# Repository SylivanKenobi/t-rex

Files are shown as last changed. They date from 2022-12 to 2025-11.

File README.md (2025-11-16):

# T-Rex

A 5x12 Ortholinear QMK and ZMK compatible Keyboard. The keyboard is designed to be easily ordered by anyone from a PCB manufacturer and assembled by yourself. It is compatible with Pro Micro controllers and their derivatives. Additionally, it supports WS2812 LED strips as an extra feature. The keyboard comes with an assortment of 3D printable cases and can be assembled with easily available parts. 

QMK Firmware is currently only on this fork of [qmk](https://github.com/SylivanKenobi/qmk_firmware/tree/master/keyboards/t_rex). 

The [ZMK](https://github.com/devilzmods/trex_shield_module) implementation supports Bluetooth and ZMK Studio with [compatible controllers](https://zmk.dev/docs/hardware#pro_micro). 

Example parts:
* [QMK Controller](https://splitkb.com/products/pro-micro-atmega32u4-5v-16mhz)
* [ZMK Controller (Wireless)](https://de.aliexpress.com/item/1005007266112508.html)
* [Diodes](https://splitkb.com/products/tht-diodes)
* [Reset button](https://mechboards.co.uk/products/reset-switches?variant=40823623090381)
* 60 Switches
* 60 Keycaps
* 6x [M2x8 Standoffs](https://splitkb.com/products/brass-m2-spacers?variant=42396969173251)
* 3D printed case([stl file](cases/minimal-case.stl))
* 6x M2x10 screws, 6x M2x5 screws

## Assembly

### PCB

1. Solder diodes on top of board, orientation is marked by silkscreen
1. Clip diode leftovers
1. Solder controller headers and reset button
1. Solder switches
1. Solder controller
1. [Flash QMK](https://github.com/SylivanKenobi/qmk_firmware/tree/master/keyboards/t_rex)
1. [Or ZMK](firmware/t_rex_zmk_studio.uf2) - Download the .uf2 file, put the board into its bootloader by double tapping reset and copy the firmware file onto the controller.
1. For wireless, solder a battery (3,7V LiIon) or battery connector and power switch to the battery pins on the nice!nano.

> If you socket your controller, mount the controller before the switches and test the PCB.

### Cases

#### Minimal Case

1. Print [case](cases/minimal-case.stl) with 3d printer
1. Mount standoffs with M2x5 from the top
1. Mount case with M2x10 to standoffs

#### Closed Case

1. Print the case, depending on printer size you can either use the regular or the split version of the case.([case files](cases/closed-falt-case)) 
1. Insert M2x4x3.5 Heat set inserts([exapmle](https://www.bastelgarage.ch/gewindeeinsatze-messing-insert-set-360-stuck))
1. Mount pcb to case with M2x5 screws

#### Slab Case

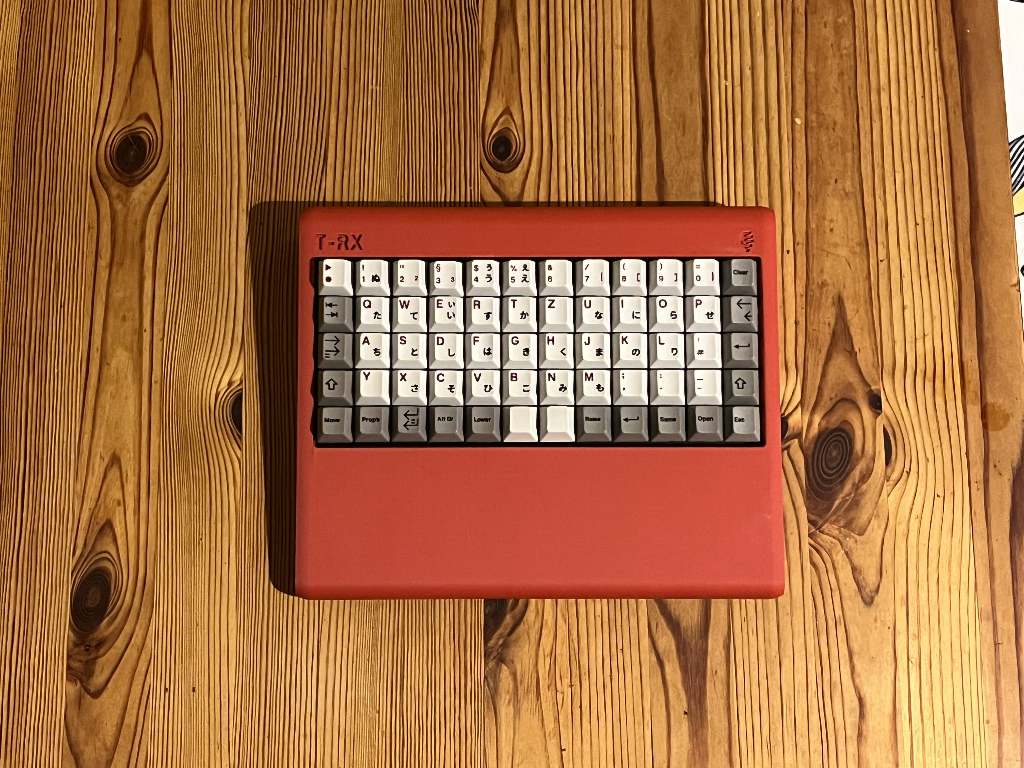
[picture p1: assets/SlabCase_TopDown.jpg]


1. Print the case, the .3mf file includes bodies for the lettering and Logo that can be colored for multicolor printing, removed for embossed text or ignored to fill the text in. Make sure the lid body sits flush on the build plate or print it separately. Only the main  Tray area of the case needs support, the battery cover can be printed in place as built-in support and popped out.[case file](cases/slabcase.3mf)
1. After printing remove the support and carefully break free the battery cover
1. Fill the case with your Medium of choice. Sand with a grain size of <2mm is recommended, other options include cement and plaster. The internal volume of the case is rougly .7 liter. Glue the lid on top and make sure it's tight in case your medium could spill out.
1. Mount 8mm standoffs to PCB with M2x5/6 from the top
1. Mount case with M2x5/6 to standoffs, if applicable route the battery connector wire into the battery tray.

## Plate

I would recommend using PCB-Mounted switches for this board. There is a 3d printable plate for the t-rex in this repo([file](cases/plate.stl)). The plate works but because it's 3d printed it's not that great.

## Customizing Firmware

(ZMK Studio)[https://zmk.studio/] allows on the fly remapping of your keyboards keymap, similar to via/vial. For more in-depth configuration you can follow the (ZMK Customization Guide)[https://zmk.dev/docs/customization] to create your own config repo and add the (T-Rex Shield Module)[https://github.com/devilzmods/trex_shield_module]

## Roadmap

1. Merge firmware to QMK

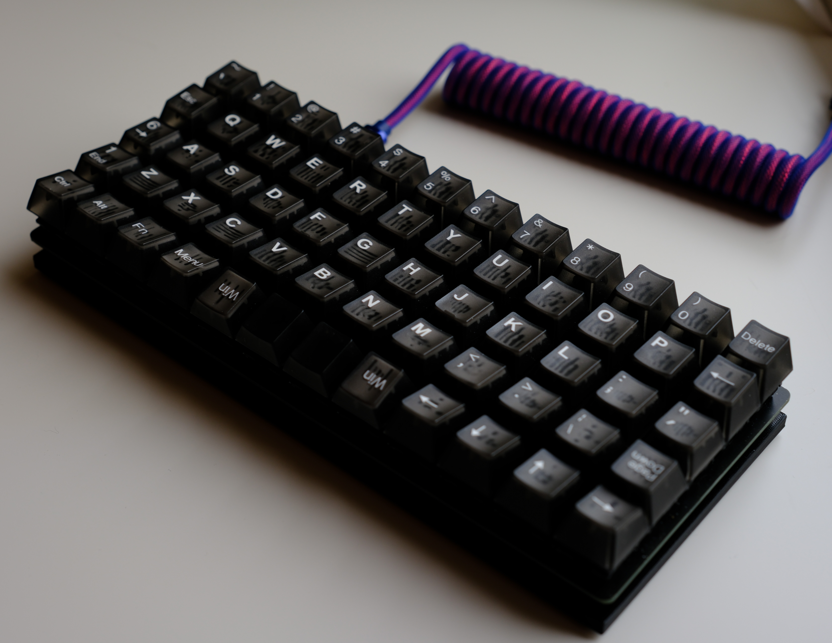
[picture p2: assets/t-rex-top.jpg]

image of keyboard backside

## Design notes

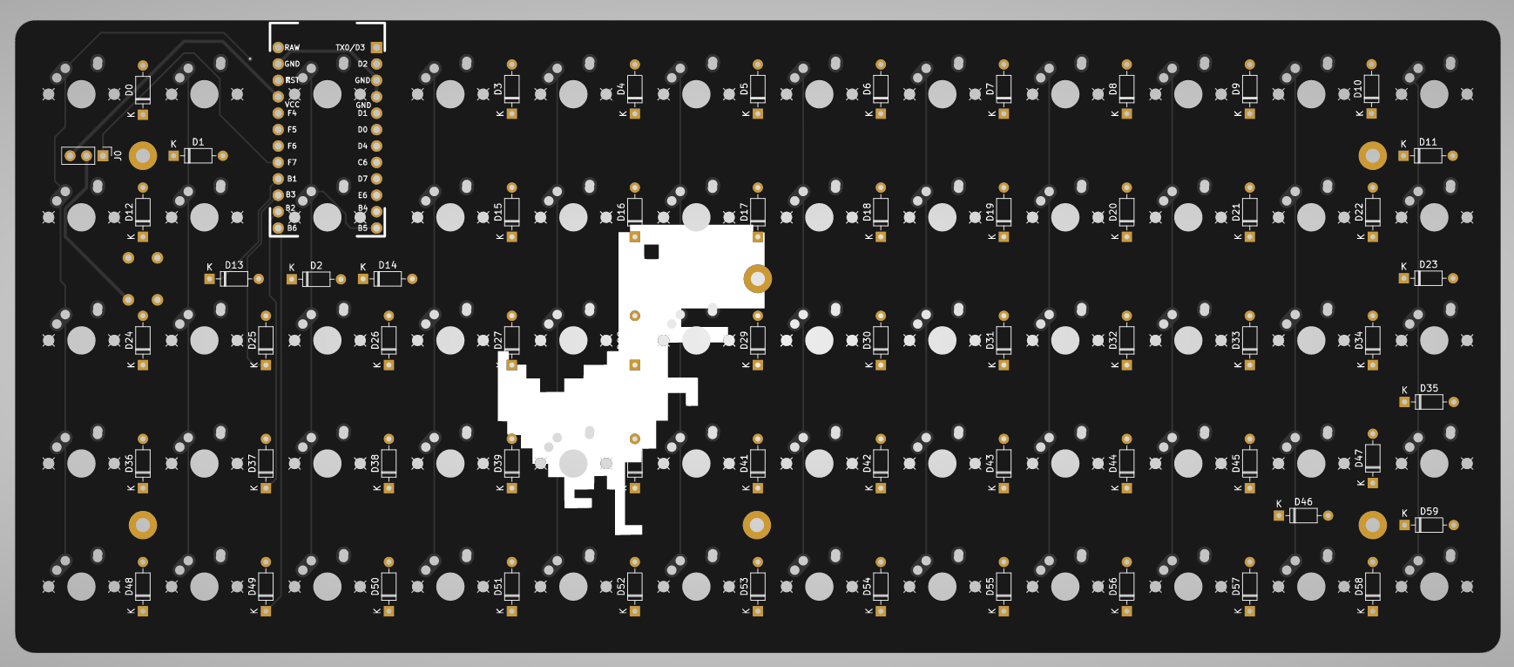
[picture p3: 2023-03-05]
assets/pcb.png

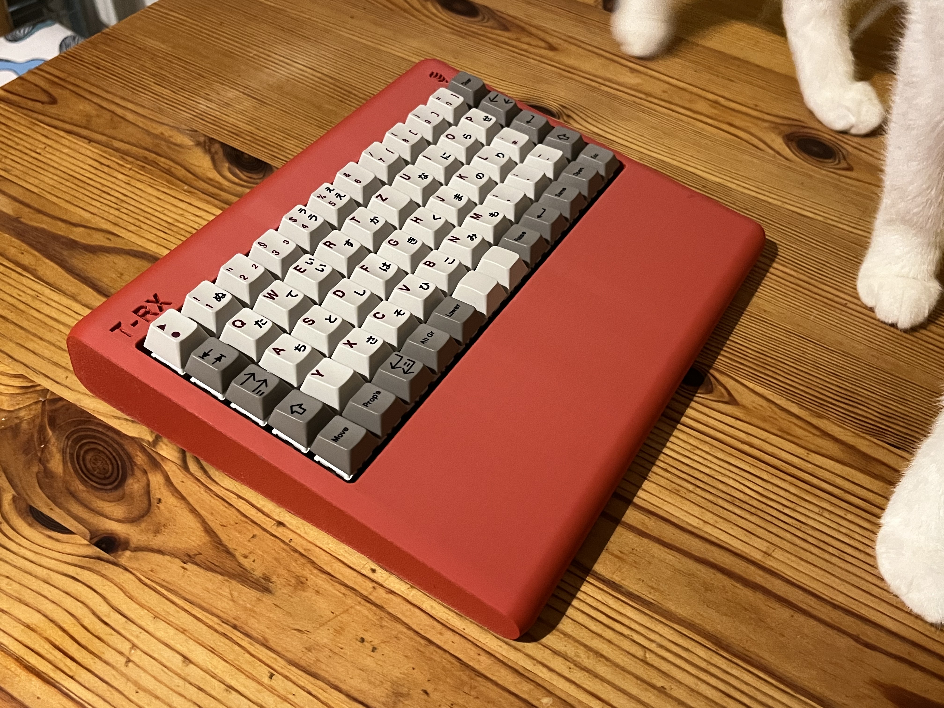
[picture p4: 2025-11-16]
assets/SlabCase_SideView.jpg

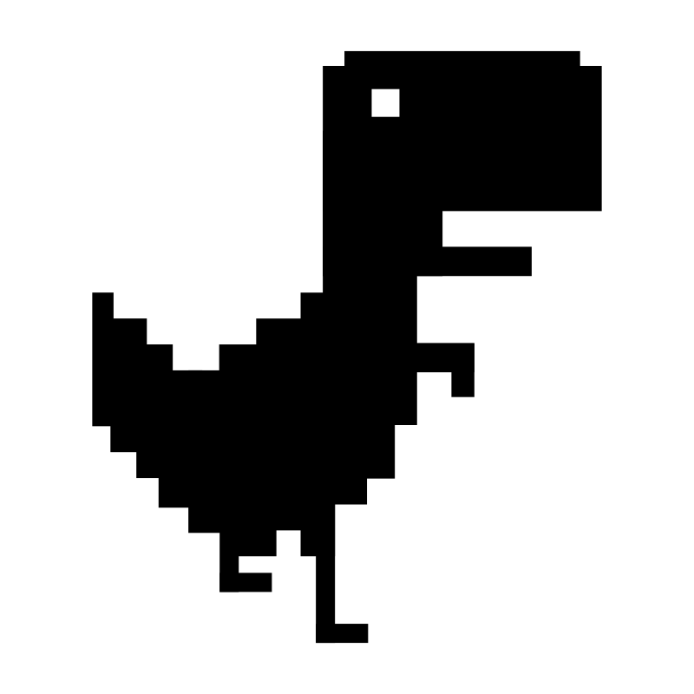
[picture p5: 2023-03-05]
assets/logo.png

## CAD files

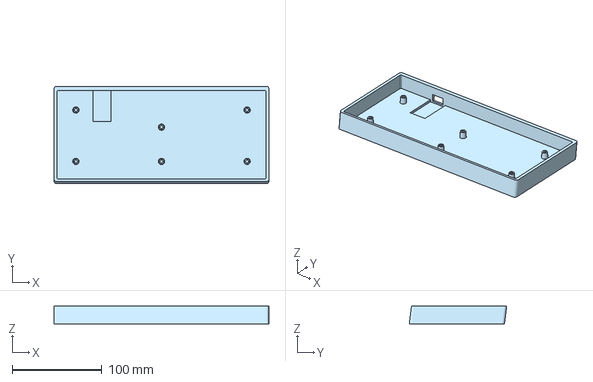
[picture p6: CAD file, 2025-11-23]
cases/closed-falt-case/regular-closed.3mf
239.2 x 108.4 x 19.9 mm

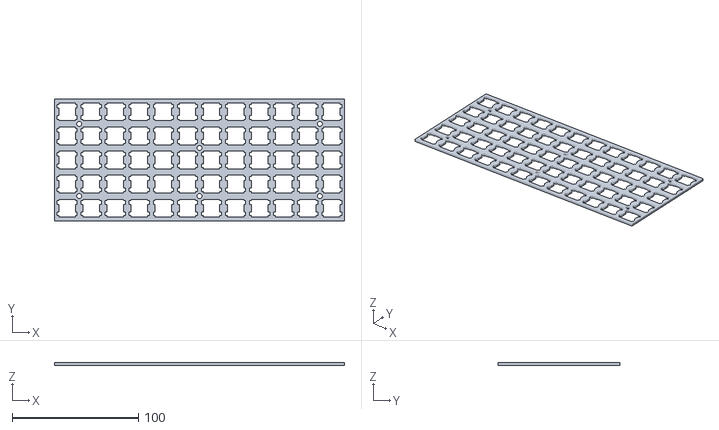
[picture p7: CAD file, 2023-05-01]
cases/plate.stl
229.6 x 96.2 x 2.00

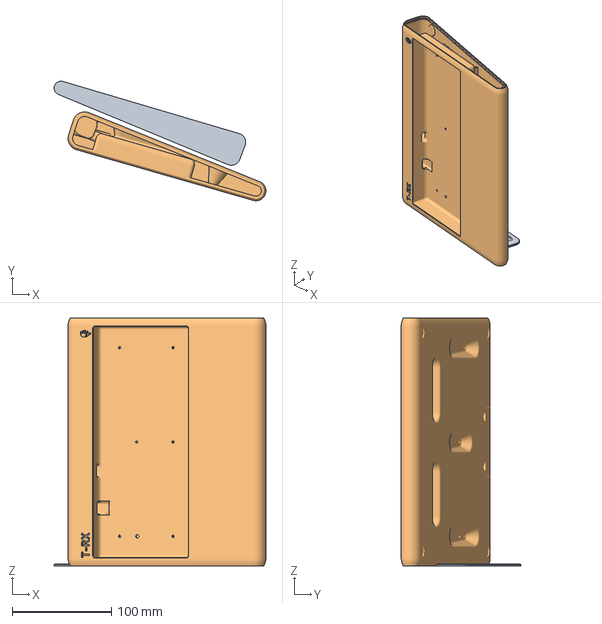
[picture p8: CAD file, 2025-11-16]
cases/slab-case/slab-case.3mf
213.4 x 120.5 x 249.8 mm
RetroWedge Lid.stl
RetroWedge v24_A

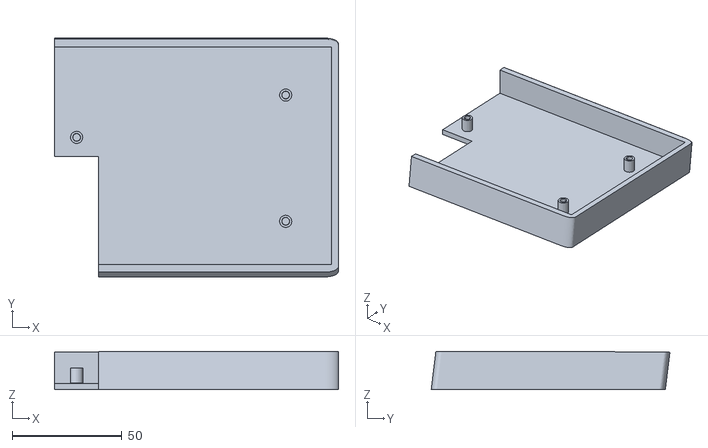
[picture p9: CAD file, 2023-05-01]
cases/closed-falt-case/split-closed-right.stl
129.5 x 108.9 x 17.5

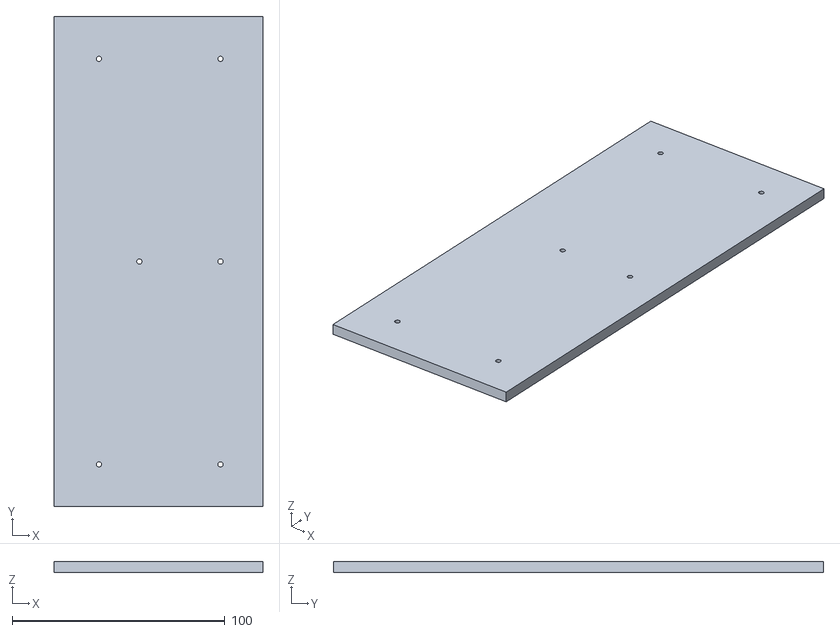
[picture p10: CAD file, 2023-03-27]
cases/minimal-case.stl
98.0 x 230.2 x 5.00

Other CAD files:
cases/closed-falt-case/split-closed-left.stl

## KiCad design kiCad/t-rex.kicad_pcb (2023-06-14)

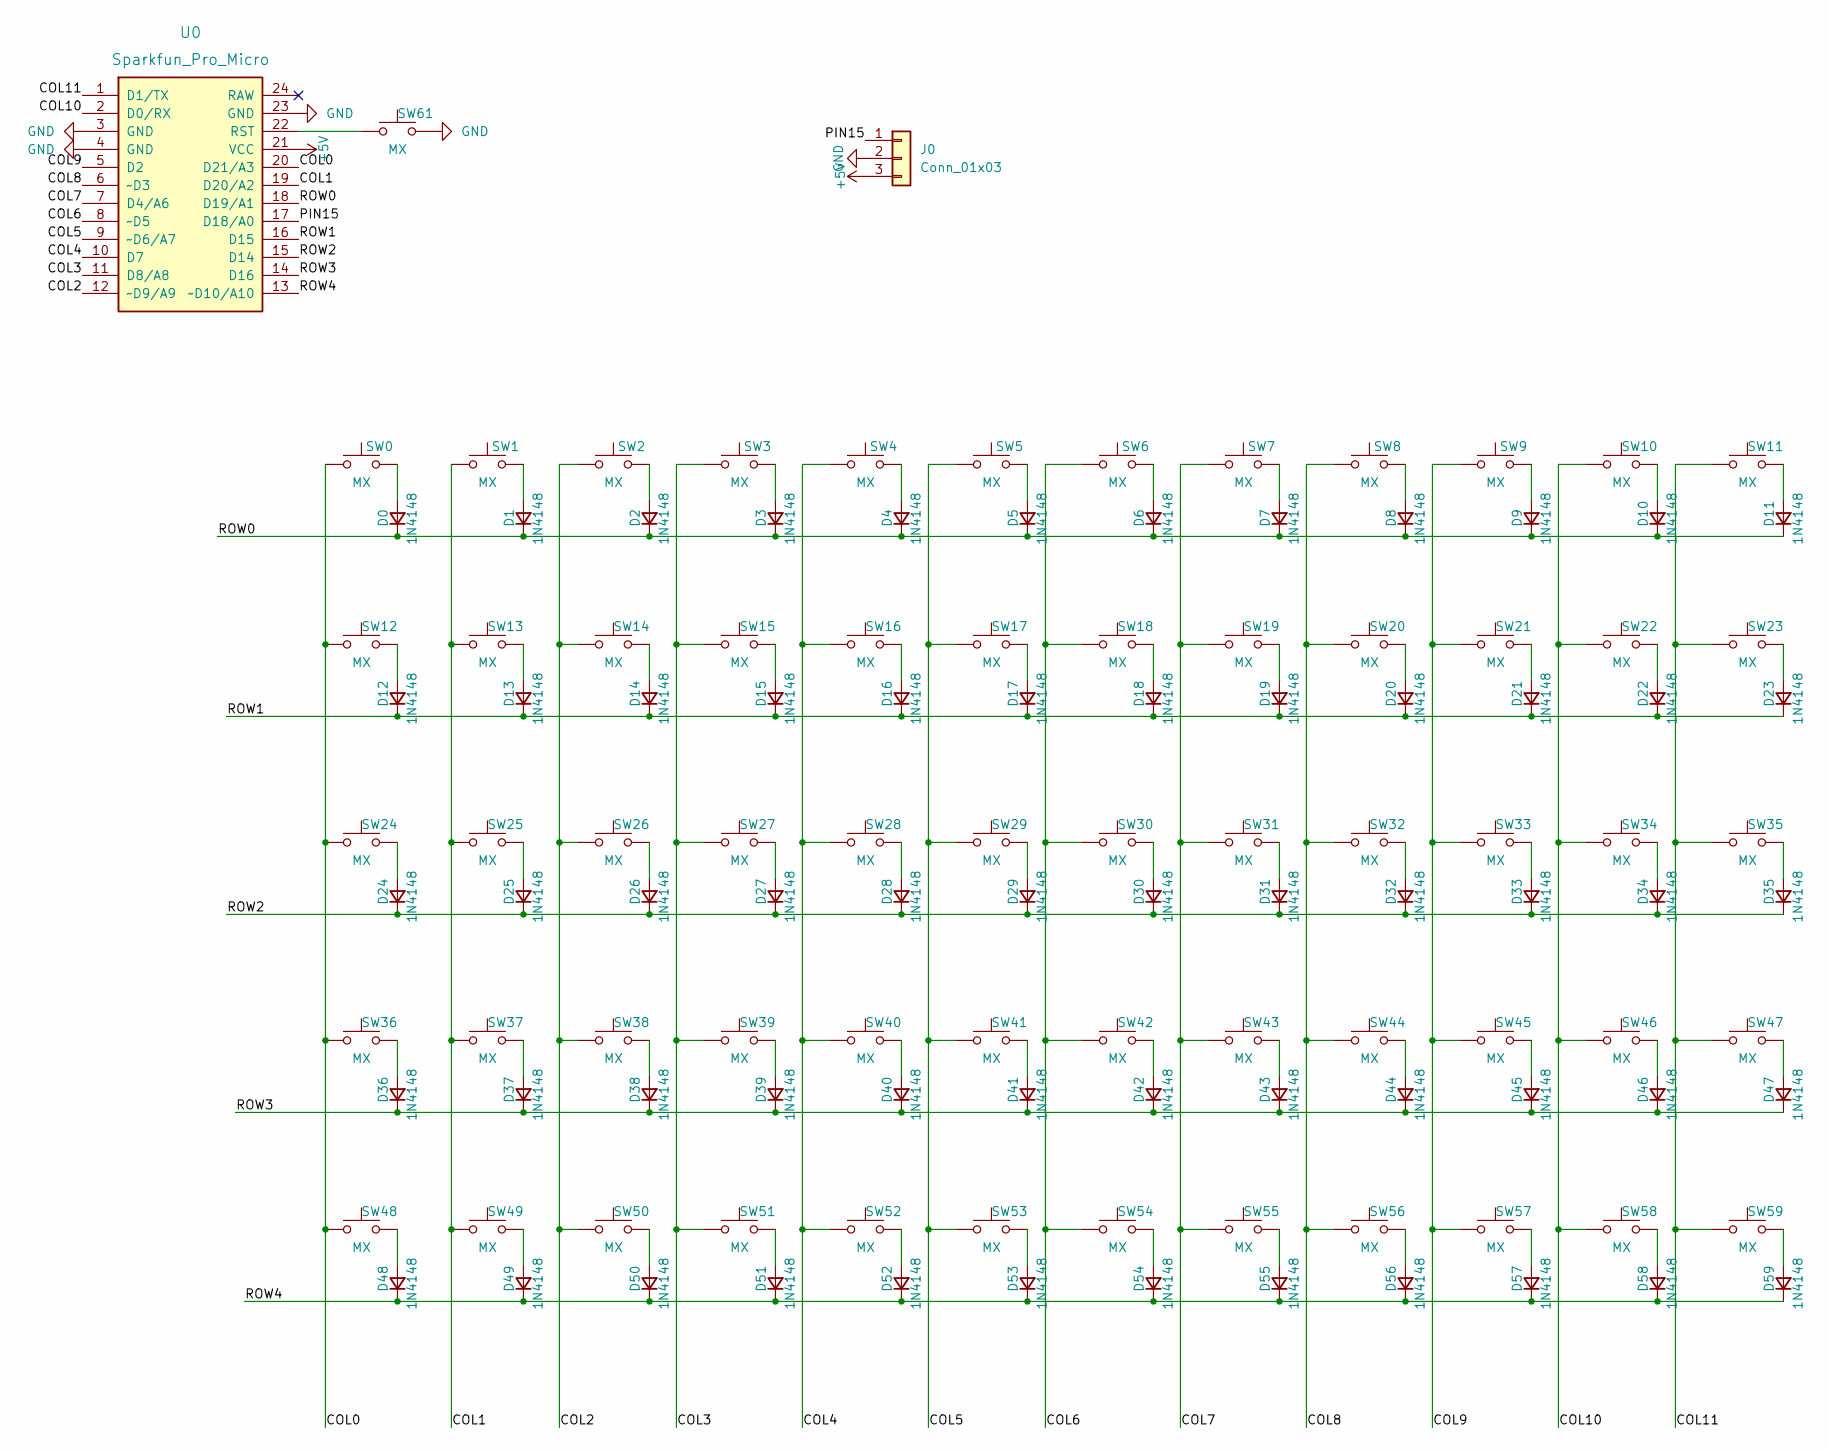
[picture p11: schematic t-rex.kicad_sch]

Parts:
D0, D1, D2, D3, D4, D5, D6, D7, D8, D9, D10, D11, D12, D13, D14, D15, D16, D17, D18, D19, D20, D21, D22, D23, D24, D25, D26, D27, D28, D29, D30, D31, D32, D33, D34, D35, D36, D37, D38, D39, D40, D41, D42, D43, D44, D45, D46, D47, D48, D49, D50, D51, D52, D53, D54, D55, D56, D57, D58, D59: 1N4148; D_DO-35_SOD27_P7.62mm_Horizontal
J0: Conn_01x03; PinHeader_1x03_P2.54mm_Vertical
SW0, SW1, SW2, SW3, SW4, SW5, SW6, SW7, SW8, SW9, SW10, SW11, SW12, SW13, SW14, SW15, SW16, SW17, SW18, SW19, SW20, SW21, SW22, SW23, SW24, SW25, SW26, SW27, SW28, SW29, SW30, SW31, SW32, SW33, SW34, SW35, SW36, SW37, SW38, SW39, SW40, SW41, SW42, SW43, SW44, SW45, SW46, SW47, SW48, SW49, SW50, SW51, SW52, SW53, SW54, SW55, SW56, SW57, SW58, SW59: MX; MX-1U-NoLED
SW61: MX; PushButton_6x6mm_TH_Pretty
U0: Sparkfun_Pro_Micro; ArduinoProMicro

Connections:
+5V: J0.3, U0.21 (VCC)
/COL0: SW0.1, SW12.1, SW24.1, SW36.1, SW48.1, U0.20 (D21/A3)
/COL1: SW1.1, SW13.1, SW25.1, SW37.1, SW49.1, U0.19 (D20/A2)
/COL2: SW2.1, SW14.1, SW26.1, SW38.1, SW50.1, U0.12 (~D9/A9)
/COL3: SW3.1, SW15.1, SW27.1, SW39.1, SW51.1, U0.11 (D8/A8)
/COL4: SW4.1, SW16.1, SW28.1, SW40.1, SW52.1, U0.10 (D7)
/COL5: SW5.1, SW17.1, SW29.1, SW41.1, SW53.1, U0.9 (~D6/A7)
/COL6: SW6.1, SW18.1, SW30.1, SW42.1, SW54.1, U0.8 (~D5)
/COL7: SW7.1, SW19.1, SW31.1, SW43.1, SW55.1, U0.7 (D4/A6)
/COL8: SW8.1, SW20.1, SW32.1, SW44.1, SW56.1, U0.6 (~D3)
/COL9: SW9.1, SW21.1, SW33.1, SW45.1, SW57.1, U0.5 (D2)
/COL10: SW10.1, SW22.1, SW34.1, SW46.1, SW58.1, U0.2 (D0/RX)
/COL11: SW11.1, SW23.1, SW35.1, SW47.1, SW59.1, U0.1 (D1/TX)
/PIN15: J0.1, U0.17 (D18/A0)
/ROW0: D0.1 (K), D1.1 (K), D2.1 (K), D3.1 (K), D4.1 (K), D5.1 (K), D6.1 (K), D7.1 (K), D8.1 (K), D9.1 (K), D10.1 (K), D11.1 (K), U0.18 (D19/A1)
/ROW1: D12.1 (K), D13.1 (K), D14.1 (K), D15.1 (K), D16.1 (K), D17.1 (K), D18.1 (K), D19.1 (K), D20.1 (K), D21.1 (K), D22.1 (K), D23.1 (K), U0.16 (D15)
/ROW2: D24.1 (K), D25.1 (K), D26.1 (K), D27.1 (K), D28.1 (K), D29.1 (K), D30.1 (K), D31.1 (K), D32.1 (K), D33.1 (K), D34.1 (K), D35.1 (K), U0.15 (D14)
/ROW3: D36.1 (K), D37.1 (K), D38.1 (K), D39.1 (K), D40.1 (K), D41.1 (K), D42.1 (K), D43.1 (K), D44.1 (K), D45.1 (K), D46.1 (K), D47.1 (K), U0.14 (D16)
/ROW4: D48.1 (K), D49.1 (K), D50.1 (K), D51.1 (K), D52.1 (K), D53.1 (K), D54.1 (K), D55.1 (K), D56.1 (K), D57.1 (K), D58.1 (K), D59.1 (K), U0.13 (~D10/A10)
GND: J0.2, SW61.2, U0.3 (GND), U0.4 (GND), U0.23 (GND)
unnamed: D0.2 (A), SW0.2
unnamed: D1.2 (A), SW1.2
unnamed: D2.2 (A), SW2.2
unnamed: D3.2 (A), SW3.2
unnamed: D4.2 (A), SW4.2
unnamed: D5.2 (A), SW5.2
unnamed: D6.2 (A), SW6.2
unnamed: D7.2 (A), SW7.2
unnamed: D8.2 (A), SW8.2
unnamed: D9.2 (A), SW9.2
unnamed: D10.2 (A), SW10.2
unnamed: D11.2 (A), SW11.2
unnamed: D12.2 (A), SW12.2
unnamed: D13.2 (A), SW13.2
unnamed: D14.2 (A), SW14.2
unnamed: D15.2 (A), SW15.2
unnamed: D16.2 (A), SW16.2
unnamed: D17.2 (A), SW17.2
unnamed: D18.2 (A), SW18.2
unnamed: D19.2 (A), SW19.2
unnamed: D20.2 (A), SW20.2
unnamed: D21.2 (A), SW21.2
unnamed: D22.2 (A), SW22.2
unnamed: D23.2 (A), SW23.2
unnamed: D24.2 (A), SW24.2
unnamed: D25.2 (A), SW25.2
unnamed: D26.2 (A), SW26.2
unnamed: D27.2 (A), SW27.2
unnamed: D28.2 (A), SW28.2
unnamed: D29.2 (A), SW29.2
unnamed: D30.2 (A), SW30.2
unnamed: D31.2 (A), SW31.2
unnamed: D32.2 (A), SW32.2
unnamed: D33.2 (A), SW33.2
unnamed: D34.2 (A), SW34.2
unnamed: D35.2 (A), SW35.2
unnamed: D36.2 (A), SW36.2
unnamed: D37.2 (A), SW37.2
unnamed: D38.2 (A), SW38.2
unnamed: D39.2 (A), SW39.2
unnamed: D40.2 (A), SW40.2
unnamed: D41.2 (A), SW41.2
unnamed: D42.2 (A), SW42.2
unnamed: D43.2 (A), SW43.2
unnamed: D44.2 (A), SW44.2
unnamed: D45.2 (A), SW45.2
unnamed: D46.2 (A), SW46.2
unnamed: D47.2 (A), SW47.2
unnamed: D48.2 (A), SW48.2
unnamed: D49.2 (A), SW49.2
unnamed: D50.2 (A), SW50.2
unnamed: D51.2 (A), SW51.2
unnamed: D52.2 (A), SW52.2
unnamed: D53.2 (A), SW53.2
unnamed: D54.2 (A), SW54.2
unnamed: D55.2 (A), SW55.2
unnamed: D56.2 (A), SW56.2
unnamed: D57.2 (A), SW57.2
unnamed: D58.2 (A), SW58.2
unnamed: D59.2 (A), SW59.2
unnamed: SW61.1, U0.22 (RST)

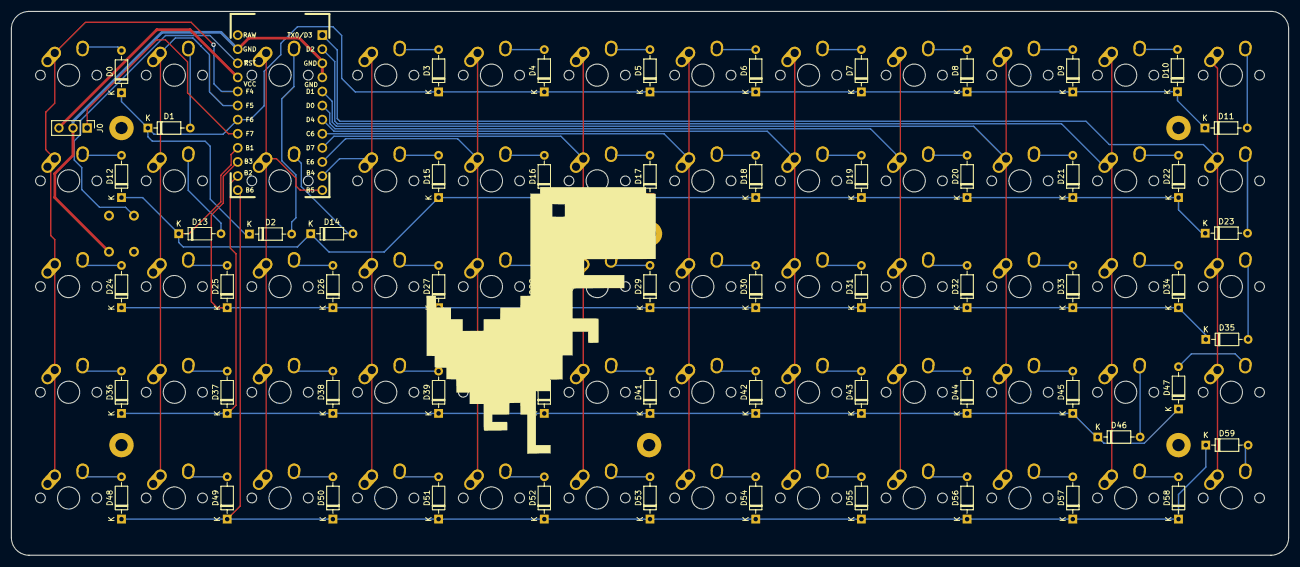
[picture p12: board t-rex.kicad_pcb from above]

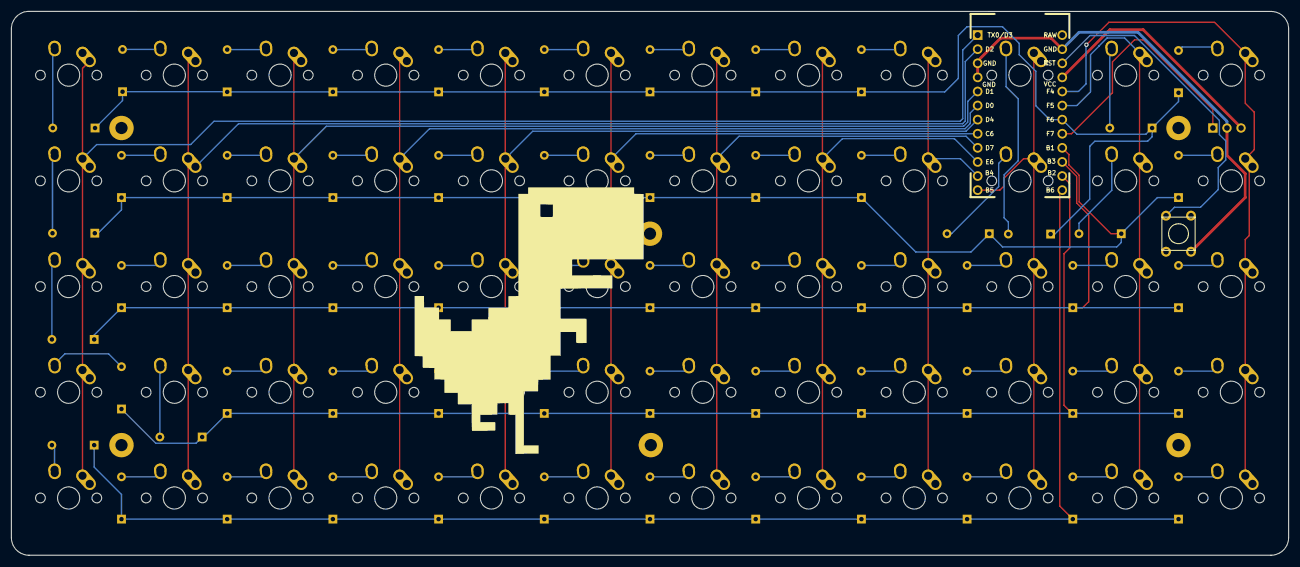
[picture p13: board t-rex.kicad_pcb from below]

Board: 2 copper layers, 230.2 x 98.0 mm, 123 parts (2 on the bottom side), 81 nets.

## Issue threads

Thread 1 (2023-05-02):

One piece case please

tangbonze, 2023-05-02:
Could you please share one piece case file? Thanks a lot.

SylivanKenobi, 2023-05-02:
Yeah i will do this probably this weekend

tangbonze, 2023-05-02:
Thank you！

SylivanKenobi, 2023-05-06:
I added it:
https://github.com/SylivanKenobi/t-rex/blob/main/cases/closed-falt-case/regular-closed.stl

Closed 2023-05-06.

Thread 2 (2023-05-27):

WS2812B support

iamagithublearner, 2023-05-27:
Hey can you please help me with configuring the WS2812B leds? where do i start?

SylivanKenobi, 2023-05-28:
Yeah sure I just start at the beginning. There are three holes on the left side of the board. The square one is data, middle is ground and the other is power. In the t-rex firmware the leds are enabled by  default. You have to configure the amount of leds that you install [here](https://github.com/SylivanKenobi/qmk_firmware/blob/343a26f16749af895945b1a97527ff421265a8eb/keyboards/t_rex/info.json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) . Everything for the leds can be configured in the [info.json](https://github.com/SylivanKenobi/qmk_firmware/blob/master/keyboards/t_rex/info.json) you can find the qmk docs for it [here](https://github.com/qmk/qmk_firmware/blob/master/docs/reference_info_json.md#rgb-lighting). Does this answer your questions or do you need something more specific?

SylivanKenobi, 2023-06-14:
I close this Issue as there was no further input for two weeks.

Closed 2023-06-14.

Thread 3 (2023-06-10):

Minimal Case

AbhinashPatro, 2023-06-10:
Hi Sylivan, How do you mount pcb to the case though ? Your PCB Gerber files contain no holes on the PCB but the picture of the back of the PCB shows the holes for passing the standoff. I am little confused on this .

SylivanKenobi, 2023-06-14:
This is a mistake. It looks like in the process of updating to kicad 7 the holes for the case mounting got lost. I will fix this today.

SylivanKenobi, 2023-06-14:
The holes are back. [Commit](https://github.com/SylivanKenobi/t-rex/commit/68a8e1d2b7005a494b37ec6a024ebed064c535c4) fixes this.

AbhinashPatro, 2023-06-18:
Thanks for fixing the bug

Closed 2023-06-14.

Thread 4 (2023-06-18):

T-rex QMK firmware Issue

AbhinashPatro, 2023-06-18:
I have built the board but am currently having issues compiling the firmware.

1. There are two missing libraries named Cihibi- OS and chibios-contrib
2. There is a missing hal_adc_lld.h file in your repository which fails qmk cli while compiling
3. Manually adding  keyboards/t_rex folder in local QMK  repo results in following error :
" platforms/chibios/drivers/vendor/RP/RP2040/ws2812_vendor.c:188:20: error: 'WS2812_DI_PIN' undeclared (first use in this function); did you mean 'WS2812_TIMING'? "

Can you please look into syncing  your repo with QMK one

SylivanKenobi, 2023-06-19:
Yeah I'll look into it

SylivanKenobi, 2023-06-19:
So the way it looks 1 and 2 are connected which are easy to fix. I'm  currently looking into No. 3. The way it looks the rgb light config has either changed or has a bug. If you disable rgblight in the [info.json](https://github.com/SylivanKenobi/qmk_firmware/blob/master/keyboards/t_rex/info.json#L14) the error doesn't occur any more.

SylivanKenobi, 2023-06-19:
It turns out that `rgblight.pin` is deprecated and is replaced with `ws2812.pin` in the info.json.  I couldn't find this change in the documentation only in the json schema.

So I synced with the qmk repo, fixed the Cihibi Issue and fixed the ws2812 pin. Now everything should work. Could you please verify that it works for you?

I'm stocked someone built this keyboard! If find more Issues or just need help I'll gladly to help.

AbhinashPatro, 2023-06-19:
Sure SylivanKenobi, Let me try this tomorrow and get back to you with more updates.

It's a pretty keyboard. People are interested in the T-rex board too.  :)

AbhinashPatro, 2023-06-25:
The QMK software looks good and works better now. Now Porting to the vial/via begins.

Thanks for the help

Closed 2023-06-25.

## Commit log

2022-11-15 add kiCad files
    [keyboard.kicad_pcb, keyboard.kicad_sch]
2022-11-15 add library submodules
    [keyboard.kicad_pcb, keyboard.kicad_sch]
2022-12-19 draw pcb, add more footprints
    [keyboard.kicad_pcb, keyboard.kicad_sch]
2023-01-17 add gerbers, fix labels
    [t-rex-B_Cu.gbl, t-rex-B_Mask.gbs, t-rex-B_Paste.gbp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]
2023-01-17 update gerbers
    [t-rex-B_Cu.gbl, t-rex-B_Mask.gbs, t-rex-B_Paste.gbp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]
2023-02-24 review changes
    [t-rex.kicad_pcb]
2023-03-05 release 1
    [t-rex-B_Cu.gbl, t-rex-B_Mask.gbs, t-rex-B_Paste.gbp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]
2023-03-27 add basic case
    [minimal-case.stl]
2023-04-09 update to kicad 7, cleanup repo
    [t-rex-B_Cu.gbl, t-rex-B_Mask.gbs, t-rex-B_Paste.gbp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]
2023-05-01 add closed case
    [closed-left.stl, closed-right.stl]
2023-05-01 add plate
    [plate.stl]
2023-05-06 add stl for closed case
    [regular-closed.stl, split-closed-left.stl, split-closed-right.stl]
2023-06-14 fix missing mount holes in pcb
    [t-rex-B_Cu.gbl, t-rex-B_Mask.gbs, t-rex-B_Paste.gbp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]
2025-11-09 Add a nice case and documentation for ZMK firmware support
    [slab-case.3mf]
2025-11-23 replace regular case with improved version
    [regular-closed.3mf, regular-closed.stl]
